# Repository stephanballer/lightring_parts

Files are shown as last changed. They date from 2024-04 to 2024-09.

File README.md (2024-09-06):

# Lightring

All important parts and files for building an addressable smart led ring which can be used for displaying the time. This is NOT a complete guide for how to build it yourself and rather a (hopefully helpful) list on what things are needed for someone with sufficient background knowledge interested in building this or something similar.

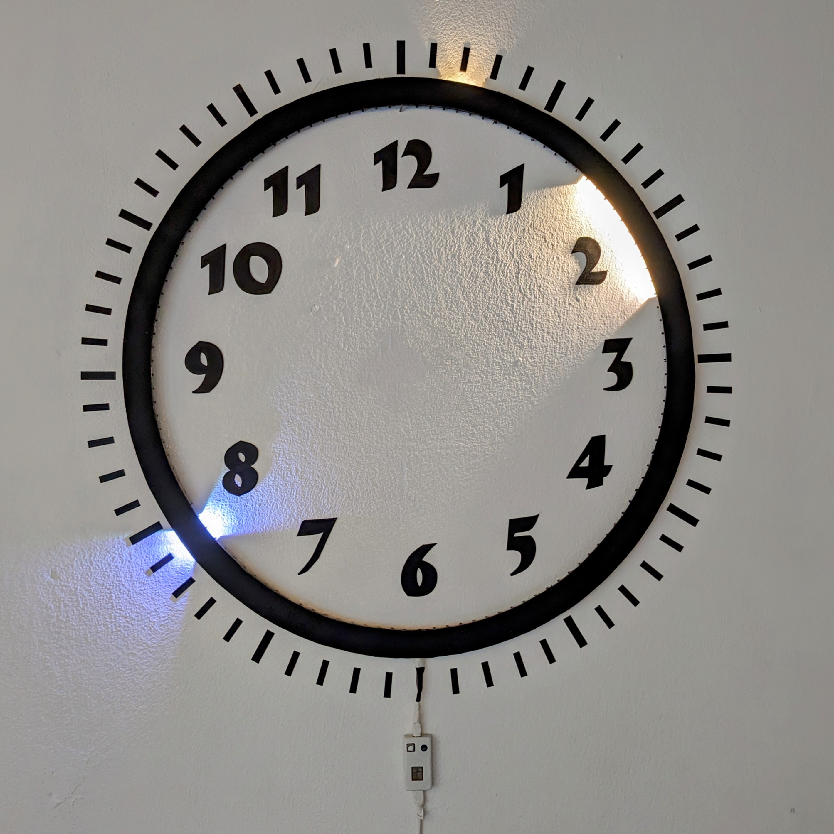
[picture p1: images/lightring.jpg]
Lightring


#### Features
- Automatic brighness adjustment (using BH1750 sensor)
- RGB+warmwhite addressable leds (SK6812)
- Tasmota web interface
  - Control color
  - Switch between modes
  - View sensor information
  - Smart home integration via MQTT
- SCD40 sensor
  - CO2 levels (second hand turns red at 1000ppm)
  - Humidity
  - Temperature (very inaccurate because of internal heating)

#### 3D Printed Parts
- 12 x frame parts
- 12 x frame clippers
- esp and sensor case

#### Electrical Parts
- esp8266 d1 mini (some may have different fits and may not be compatible with the provided PCB!!!) [link](https://de.aliexpress.com/item/32651747570.html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)
- 4 x sk6812 light strip (RGBWW; 1m; 60 leds; IP30) [link](https://de.aliexpress.com/item/32476317187.html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)
- EasyEDA PCB (you have to order yourself [here](https://easyeda.com/editor) using the EasyEDA_pcb.json)
- SCD40 sensor [link](https://de.aliexpress.com/item/1005005061351244.html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)
- BH1750 sensor [link](https://de.aliexpress.com/item/32672074071.html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)

#### Software
  - ESP Home: `esphome run lightring.yml`
  - [Custom Tasmota version](https://github.com/stephanballer/lightring_tasmota)

#### Useful commands to configure Tasmota
  - Clock mode: ```scheme 5```
  - Set amount of leds: ```pixels 240```
  - Make clock go counterclockwise: ```setoption16 1``` 
  - 2 channels for RGB and WW: ```setoption68 1```
  - Set hand colors (for WW set R=00 and G=B, e.g. RGB <- 001212):
    - Second (white): ```color3 FFFFFF```
    - Minute (warmwhite): ```color4 00FFFF```
    - Hour (warmwhite): ```color5 00FFFF```
    - Marker (off): ```color6 000000```
  - Let second hand turn red if CO2 levels too high: ```Rule1 on SCD40#CarbonDioxide>1000 do color3 #FF0000 endon on SCD40#CarbonDioxide<=1000 do color3 #FFFFFF endon"```
  - Rotate around 60 pixels: ```rotation 60```

#### Tasmota module config
  - D2 -> I2C SDA
  - D1 -> I2C SCL
  - D5 -> WS2812

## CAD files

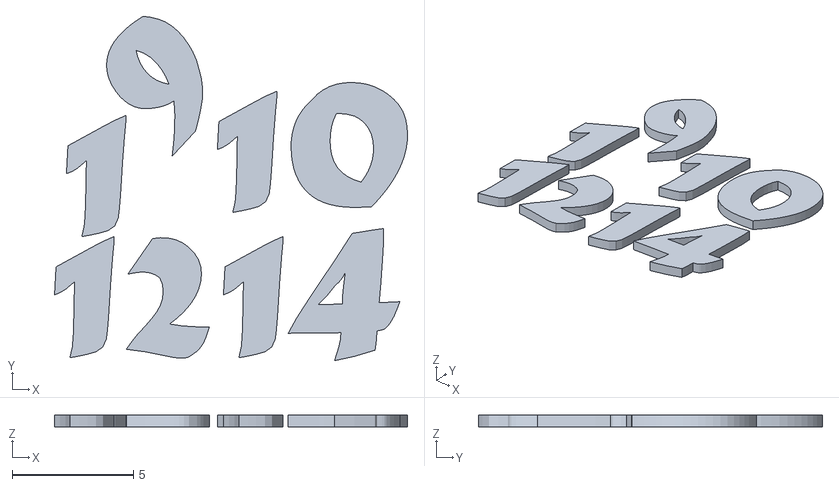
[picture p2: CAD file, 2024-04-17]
numbers_1.stl
14.6 x 14.2 x 0.5

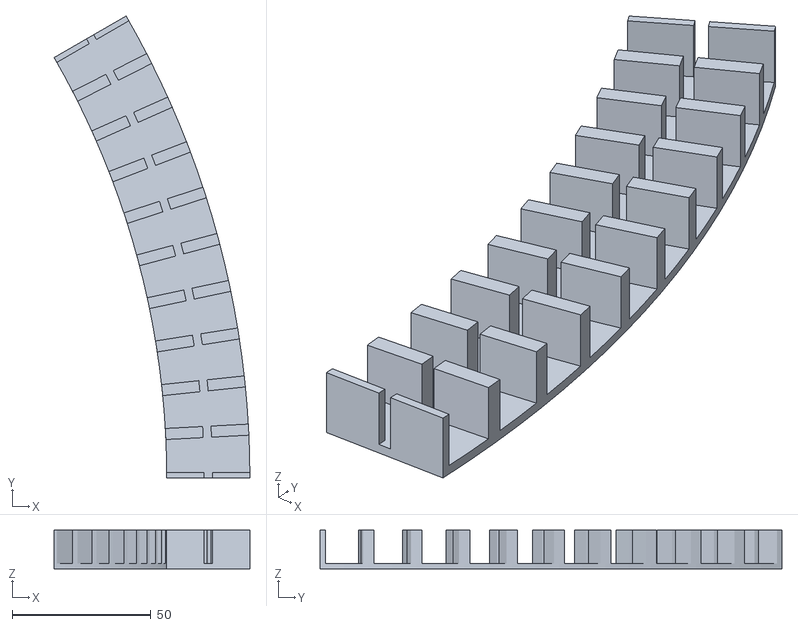
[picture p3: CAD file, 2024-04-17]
frame_part_12.stl
70.6 x 166.7 x 14.0

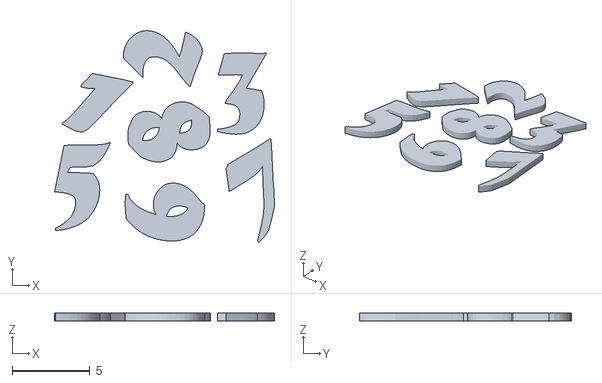
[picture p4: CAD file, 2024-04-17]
numbers_2.stl
14.2 x 13.6 x 0.5

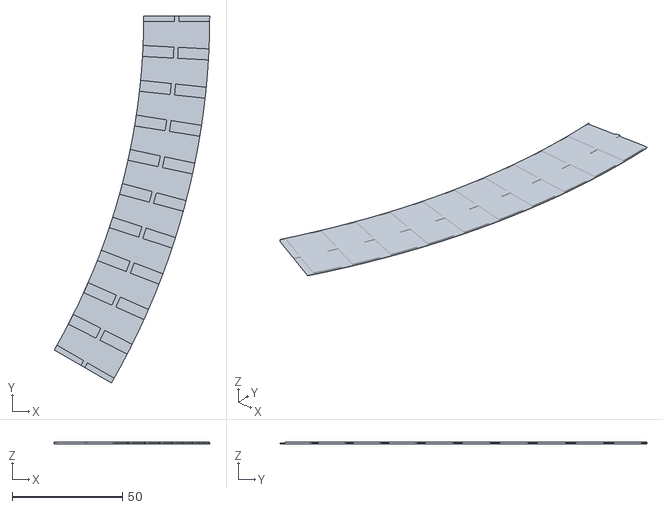
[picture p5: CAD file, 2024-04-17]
frame_part_12_clip.stl
70.6 x 166.7 x 1.00

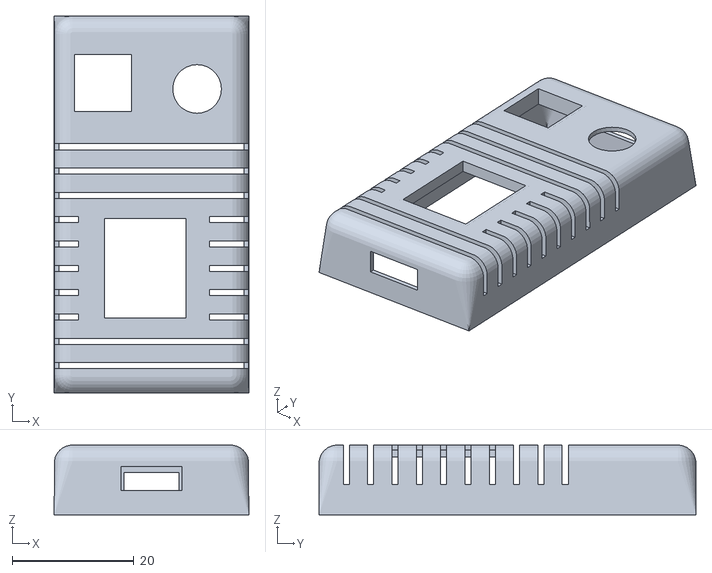
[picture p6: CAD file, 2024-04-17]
esp8266_sensor_case.stl
32.0 x 62.0 x 11.5

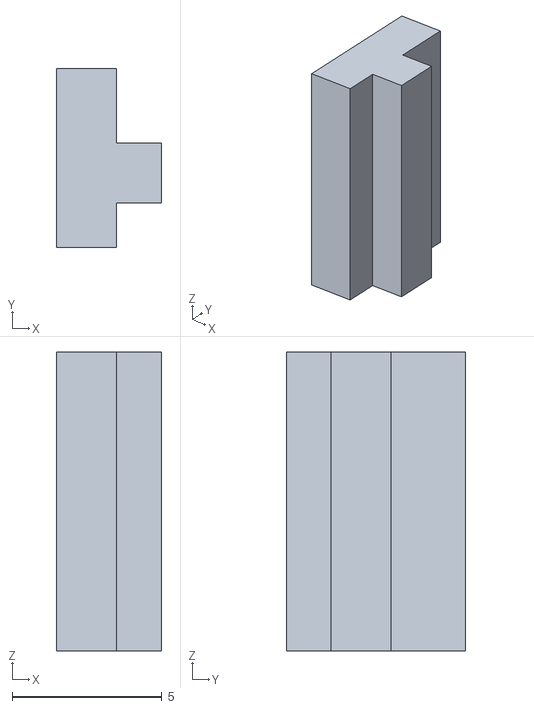
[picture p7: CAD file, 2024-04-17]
led_distancer.stl
3.50 x 6.00 x 10.0

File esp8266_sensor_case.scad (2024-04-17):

$fn = 28;

module box_whole(dim_inner_w, dim_inner_l, dim_inner_h, wall_thickness, tolerance, radius)
{

    scd40_inner_distance = 2;
    esp_inner_distance = 1;

    union()
    {
        // sealing wall for esp
        difference(){
            translate([ 7 - tolerance, 11 - tolerance, dim_inner_h - esp_inner_distance])
            cube([ 14 + 2 * tolerance, 17 + 2 * tolerance, esp_inner_distance + wall_thickness ]);
            translate([ 7.5 - tolerance, 11.5 - tolerance, dim_inner_h - esp_inner_distance-wall_thickness ])
            cube([ 13 + 2 * tolerance, 16 + 2 * tolerance, esp_inner_distance * 4*wall_thickness ]);
        }
        //sealing wall for scd40
        difference()
        {
            translate([ 2 - tolerance, 45 - tolerance, dim_inner_h -scd40_inner_distance])
                cube([ 10 + 2 * tolerance, 10 + 2 * tolerance, scd40_inner_distance + wall_thickness]);
            translate([ 2.5 - tolerance, 45.5 - tolerance, dim_inner_h - scd40_inner_distance-wall_thickness ])
                cube([ 9 + 2 * tolerance, 9 + 2 * tolerance, scd40_inner_distance + 3 * wall_thickness ]);
        }
        difference()
        {
            union()
            {
                // the case itself without the holes
                hull()
                {
                    // spheres to make 4 upper rounded corners
                    translate(
                        [ radius - wall_thickness, radius - wall_thickness, dim_inner_h - radius + wall_thickness ])
                        sphere(r = radius);
                    translate([
                        dim_inner_w - radius + wall_thickness, radius - wall_thickness, dim_inner_h - radius +
                        wall_thickness
                    ]) sphere(r = radius);
                    translate([
                        radius - wall_thickness, dim_inner_l - radius + wall_thickness, dim_inner_h - radius +
                        wall_thickness
                    ]) sphere(r = radius);
                    translate([
                        dim_inner_w - radius + wall_thickness, dim_inner_l - radius + wall_thickness,
                        dim_inner_h - radius +
                        wall_thickness
                    ]) sphere(r = radius);
                    
                    // bottom square
                    translate([ -wall_thickness, -wall_thickness, -wall_thickness ])
                        cube([ dim_inner_w + 2 * wall_thickness, dim_inner_l + 2 * wall_thickness, wall_thickness ]);
                }
            }
            union()
            {
                // smaller version of the case to make it hollow
                hull()
                {
                    // spheres to make 4 upper rounded corners
                    translate([ radius - tolerance, radius - tolerance, dim_inner_h - radius + tolerance ])
                        sphere(r = radius);
                    translate(
                        [ dim_inner_w - radius + tolerance, radius - tolerance, dim_inner_h - radius + tolerance ])
                        sphere(r = radius);
                    translate(
                        [ radius - tolerance, dim_inner_l - radius + tolerance, dim_inner_h - radius + tolerance ])
                        sphere(r = radius);
                    translate([
                        dim_inner_w - radius + tolerance, dim_inner_l - radius + tolerance, dim_inner_h - radius +
                        tolerance
                    ]) sphere(r = radius);

                    // bottom square
                    translate([ -tolerance, -tolerance, -tolerance ])
                        cube([ dim_inner_w + 2 * tolerance, dim_inner_l + 2 * tolerance, wall_thickness ]);
                }
                // usb hole
                translate([ 10, -2 * wall_thickness, 4 ]) cube([ 10, 3 * wall_thickness, 4 ]);

                // esp hole
                translate([ 7.5 - tolerance, 11.5 - tolerance, dim_inner_h - wall_thickness ])
                    cube([ 13 + 2 * tolerance, 16 + 2 * tolerance, 3 * wall_thickness ]);

                // scd40 hole
                translate([ 2.5 - tolerance, 45.5 - tolerance, dim_inner_h - wall_thickness ])
                    cube([ 9 + 2 * tolerance, 9 + 2 * tolerance, 3 * wall_thickness ]);

                // brighness sensor hole
                translate([ 22.5, 49, dim_inner_h - wall_thickness ]) cylinder(h = 3 * wall_thickness, r1 = 4, r2 = 4);

                // leds socket hole: 2 options
                //translate([10.5,dim_inner_l-wall_thickness,4])cube([9,3*wall_thickness,7 + wall_thickness]);
                translate([ 10.5, dim_inner_l - wall_thickness, 4 ]) cube([ 9, 3 * wall_thickness, 3 ]);

                // air holes
                translate([ -2, 3, 5 ])cube([ 40, 1, 10 ]);
                translate([ -2, 7, 5 ])cube([ 40, 1, 10 ]);
                translate([ -2, 11, 5 ])cube([ 5, 1, 10 ]);
                translate([ -2, 15, 5 ])cube([ 5, 1, 10 ]);
                translate([ -2, 19, 5 ])cube([ 5, 1, 10 ]);
                translate([ -2, 23, 5 ])cube([ 5, 1, 10 ]);
                translate([ -2, 27, 5 ])cube([ 5, 1, 10 ]);
                translate([ 24.5, 11, 5 ])cube([ 7, 1, 10 ]);
                translate([ 24.5, 15, 5 ])cube([ 7, 1, 10 ]);
                translate([ 24.5, 19, 5 ])cube([ 7, 1, 10 ]);
                translate([ 24.5, 23, 5 ])cube([ 7, 1, 10 ]);
                translate([ 24.5, 27, 5 ])cube([ 7, 1, 10 ]);
                translate([ -2, 31, 5 ])cube([ 40, 1, 10 ]);
                translate([ -2, 35, 5 ])cube([ 40, 1, 10 ]);
                translate([ -2, 39, 5 ])cube([ 40, 1, 10 ]);
            };
        };
    };
};

module box_top(dim_inner_w, dim_inner_l, dim_inner_h, wall_thickness, tolerance, radius)
{
    difference()
    {
        box_whole(dim_inner_w, dim_inner_l, dim_inner_h, wall_thickness, tolerance, radius);
        translate([ -2 * wall_thickness, -2 * wall_thickness, -2 * wall_thickness ])
            cube([ dim_inner_w + 4 * wall_thickness, dim_inner_l + 4 * wall_thickness, 2 * wall_thickness ]);
    }
}

// in progress, this was intendet to be the bottom part but figured out it wasn't necessary
//module box_bottom(dim_inner_w, dim_inner_l, dim_inner_h, wall_thickness, tolerance, radius)
//{
//    difference()
//    {
//        box_whole(dim_inner_w, dim_inner_l, dim_inner_h, wall_thickness, tolerance, radius);
//        translate([ -2 * wall_thickness, -2 * wall_thickness, dim_inner_h / 2 ]) cube([
//            dim_inner_w + 4 * wall_thickness, dim_inner_l + 4 * wall_thickness, dim_inner_h / 2 + 2 * wall_thickness
//        ]);
//    }
//}

dim_inner_w = 30;
dim_inner_l = 60;
dim_inner_h = 10.5;
wall_thickness = 1;
tolerance = 0.2;
radius = 3;
box_top(dim_inner_w, dim_inner_l, dim_inner_h, wall_thickness, tolerance, radius);

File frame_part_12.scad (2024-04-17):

module ring (ring_height = 2,
    r1 = 333.310,
    r2 = 303.310,
    light_gap_inner = 1.5,
    light_gap_outer = 1.5,
    sep_thickness = 4,
    sep_height = 12,
    $fn = 240) {

    sep_length_outer = (r1 - r2 - light_gap_outer*2) / 2;
    sep_length_inner = (r1 - r2 - light_gap_inner*2) / 2;


    difference() {
        union() {
            difference() {
                cylinder(h = ring_height, r1 = r1, r2 = r1, center = true);
                cylinder(h = ring_height+1, r1 = r2, r2 = r2, center = true);
            };
    
            for (i = [90:100])
            rotate(i * 3){
                translate([0, r2 + sep_length_inner / 2, sep_height / 2 + ring_height / 2]) {
                    cube(size = [sep_thickness, sep_length_inner, sep_height], center = true);
                }
                translate([0, r1 - sep_length_outer / 2, sep_height / 2 + ring_height / 2]) {
                    cube(size = [sep_thickness, sep_length_outer, sep_height], center = true);
                }
            }
        }

        translate([0, 0, -ring_height/2 - 1]) {
            translate([-r1-1, -r1-1, 0]) {
                cube([r1+1, 2*r1+1, sep_height + ring_height + 2], center = false);
            }
            translate([-r1-1, -r1-1, 0]) {
                cube([2*r1+2, r1+1, sep_height + ring_height + 2], center = false);
            }
            rotate(30) {
                cube([r1+1, r1+1, sep_height + ring_height + 2], center = false);
            }
        }
    }
}

module inv_ring (ring_height = 1,
    r1 = 333.310,
    r2 = 303.310,
    light_gap_inner = 1.5,
    light_gap_outer = 1.5,
    sep_thickness = 4,
    sep_height = 12,
    $fn = 240,
    tolerance = 0.5) {

    rotate([0,180,180]) difference() {
        difference() {
            cylinder(h = ring_height, r1 = r1, r2 = r1, center = true);
            cylinder(h = ring_height+1, r1 = r2, r2 = r2, center = true);
        };
    
        translate([0, 0, -ring_height/2 - 1]) {
            translate([-r1-1, -r1-1, 0]) {
                cube([r1+1, 2*r1+1, sep_height + ring_height + 2], center = false);
            }
            translate([-r1-1, -r1-1, 0]) {
                cube([2*r1+2, r1+1, sep_height + ring_height + 2], center = false);
            }
            rotate(30) {
                cube([r1+1, r1+1, sep_height + ring_height + 2], center = false);
            }
        }

        translate([0, 0, -sep_height-ring_height/2]) ring(ring_height, r1, r2, light_gap_inner - tolerance, light_gap_outer - tolerance, sep_thickness + tolerance*2, sep_height, $fn);
    }
}


//ring_height = 2;
//r1 = 333.310;
//r2 = 303.310;
//light_gap = 3;
//sep_thickness = 4;
//sep_height = 12;
//tolerance = 0.5;
//
//difference(){
//inv_ring();
////ring();
//translate([0,0,-1])
//difference(){
//cylinder(h=2, r1=r2, r2=r2+(r1 - r2)/2, $fn=240);
//rotate([0,180,180])translate([0, 0, -sep_height-ring_height/2]) ring(ring_height, r1, r2, light_gap - tolerance*2, sep_thickness + tolerance*2, sep_height, $fn);
//}
//}


//        difference(){
//            difference() {
//                cylinder(h = ring_height+1, r1 = r1, r2 = r1, center = true);
//                cylinder(h = ring_height+2, r1 = r2, r2 = r2, center = true);
//
//            };
//
//            difference() {
//                cylinder(h = ring_height+3, r1 = r1-sep_length, r2 = r1-sep_length, center = true);
//                cylinder(h = ring_height+4, r1 = r2+sep_length, r2 = r2+sep_length, center = true);
//            };
//
//            for (i = [80:90])
//            rotate(i * 3){
//                translate([0, r2 + sep_length / 2, -ring_height]) {
//                    cube(size = [sep_thickness+4*tolerance, r1, 2*sep_height], center = true);
//                }
//            };
//        }

inv_ring();
//ring();

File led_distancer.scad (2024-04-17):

translate([0,1.5,0])cube(size=[3.5, 2, 10]);
translate([0,0,0])cube(size=[2, 6, 10]);

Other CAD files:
frame_part_12_alt.scad
